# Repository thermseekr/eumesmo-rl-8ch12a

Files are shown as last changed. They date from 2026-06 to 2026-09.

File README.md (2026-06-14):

# eumesmo-rl-8ch12a

Relay board with 8x 24 VDC NO relays. This board is designed to be used togheter with [eumesmo-io-24v16ch](https://github.com/thermseekr/eumesmo-io-24v16ch), but can be driven by any 24V control circuit compatible with NPN inputs. It uses Omron 16A relays and is limited to 12A/channel per copper trace capacity.

The board is compatible with the SP7 DIN rail system from Metaltex.

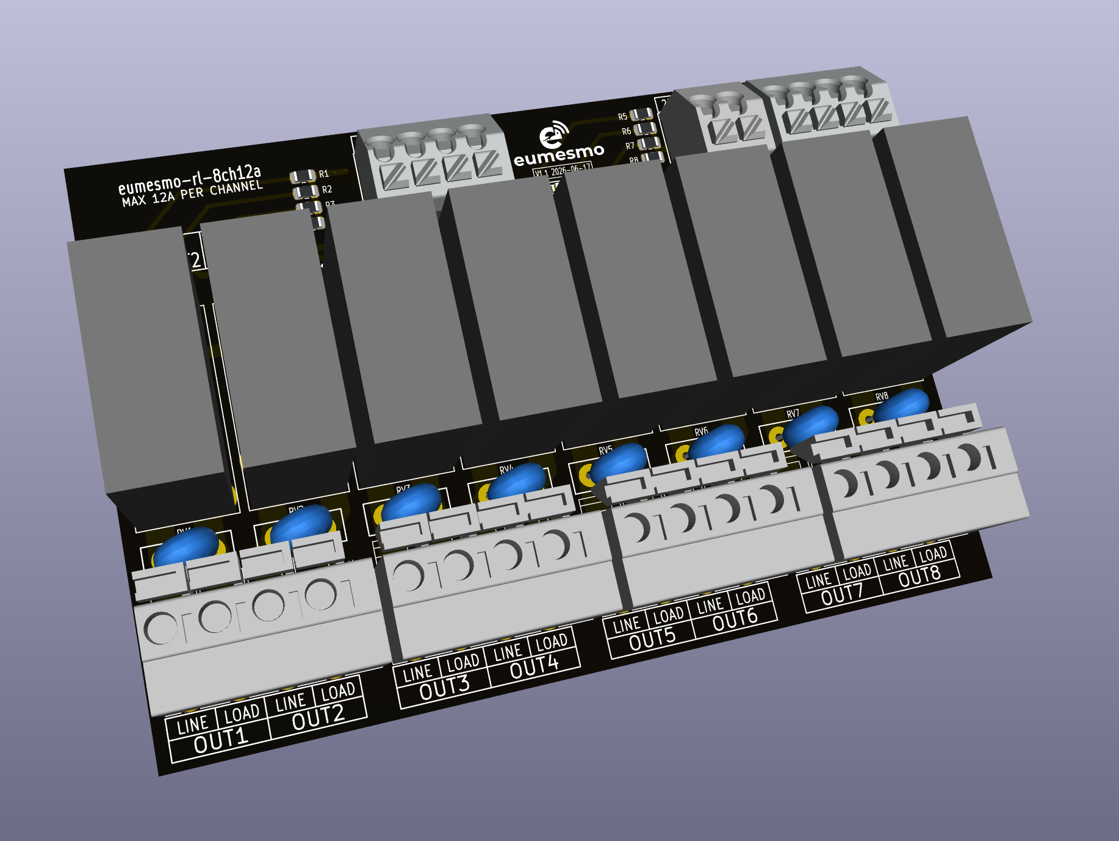
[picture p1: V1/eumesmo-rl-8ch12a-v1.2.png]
eumesmo-rl-8ch12a


## VERSION HISTORY

V1.2 - 2026/06/13 - Repository renamed from RELAY-24V-8CH-12A to eumesmo-rl-8ch12A to align the design with the eumesmo line of building automation products.

V1.1 - 2026/06/13 - Input terminal blocks replaced from 2.54mm to 3.5mm pitch for easier installation in the field.

V1.0 - 2024/11/24 - Initial release.

## LICENSE

This project is licensed under the [Creative Commons BY-NC 4.0 License](https://creativecommons.org/licenses/by-nc/4.0/).
Commercial use is not permitted without prior written consent. See the [LICENSE.txt](LICENSE.txt) file for details.

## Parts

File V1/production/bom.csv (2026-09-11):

Designator | Footprint | Quantity | Value | LCSC Part #
D1, D11, D13, D15, D3, D5, D7, D9 | 0603 | 8 | ORANGE/0603 | C2987557
D10, D12, D14, D16, D2, D4, D6, D8 | D_SOD-123 | 8 | 1N4148 | C81598
J1 | TerminalBlock_Wago_250-202_1x02_P3.5mm_45Degree | 1 | 250-202 | C2765061
J2, J3 | TerminalBlock_Wago_250-204_1x04_P3.5mm_45Degree | 2 | 250-204 | C2765063
J4, J5, J6, J7 | TerminalBlock_Dibo_DB142V-5.08-4P_1x04_P5.08mm_Vertical | 4 | DB142V-5.08-4P | C2898701
K1, K2, K3, K4, K5, K6, K7, K8 | Relay_SPST_Omron_G5PZ-1A | 8 | G5PZ-1A | C6719448
R1, R2, R3, R4, R5, R6, R7, R8 | 0805 | 8 | 10k/125mW | C17414
RV1, RV2, RV3, RV4, RV5, RV6, RV7, RV8 | RV_Disc_D9.50mm_W3.6mm_P5.08mm | 8 | 275VAC | C2761646

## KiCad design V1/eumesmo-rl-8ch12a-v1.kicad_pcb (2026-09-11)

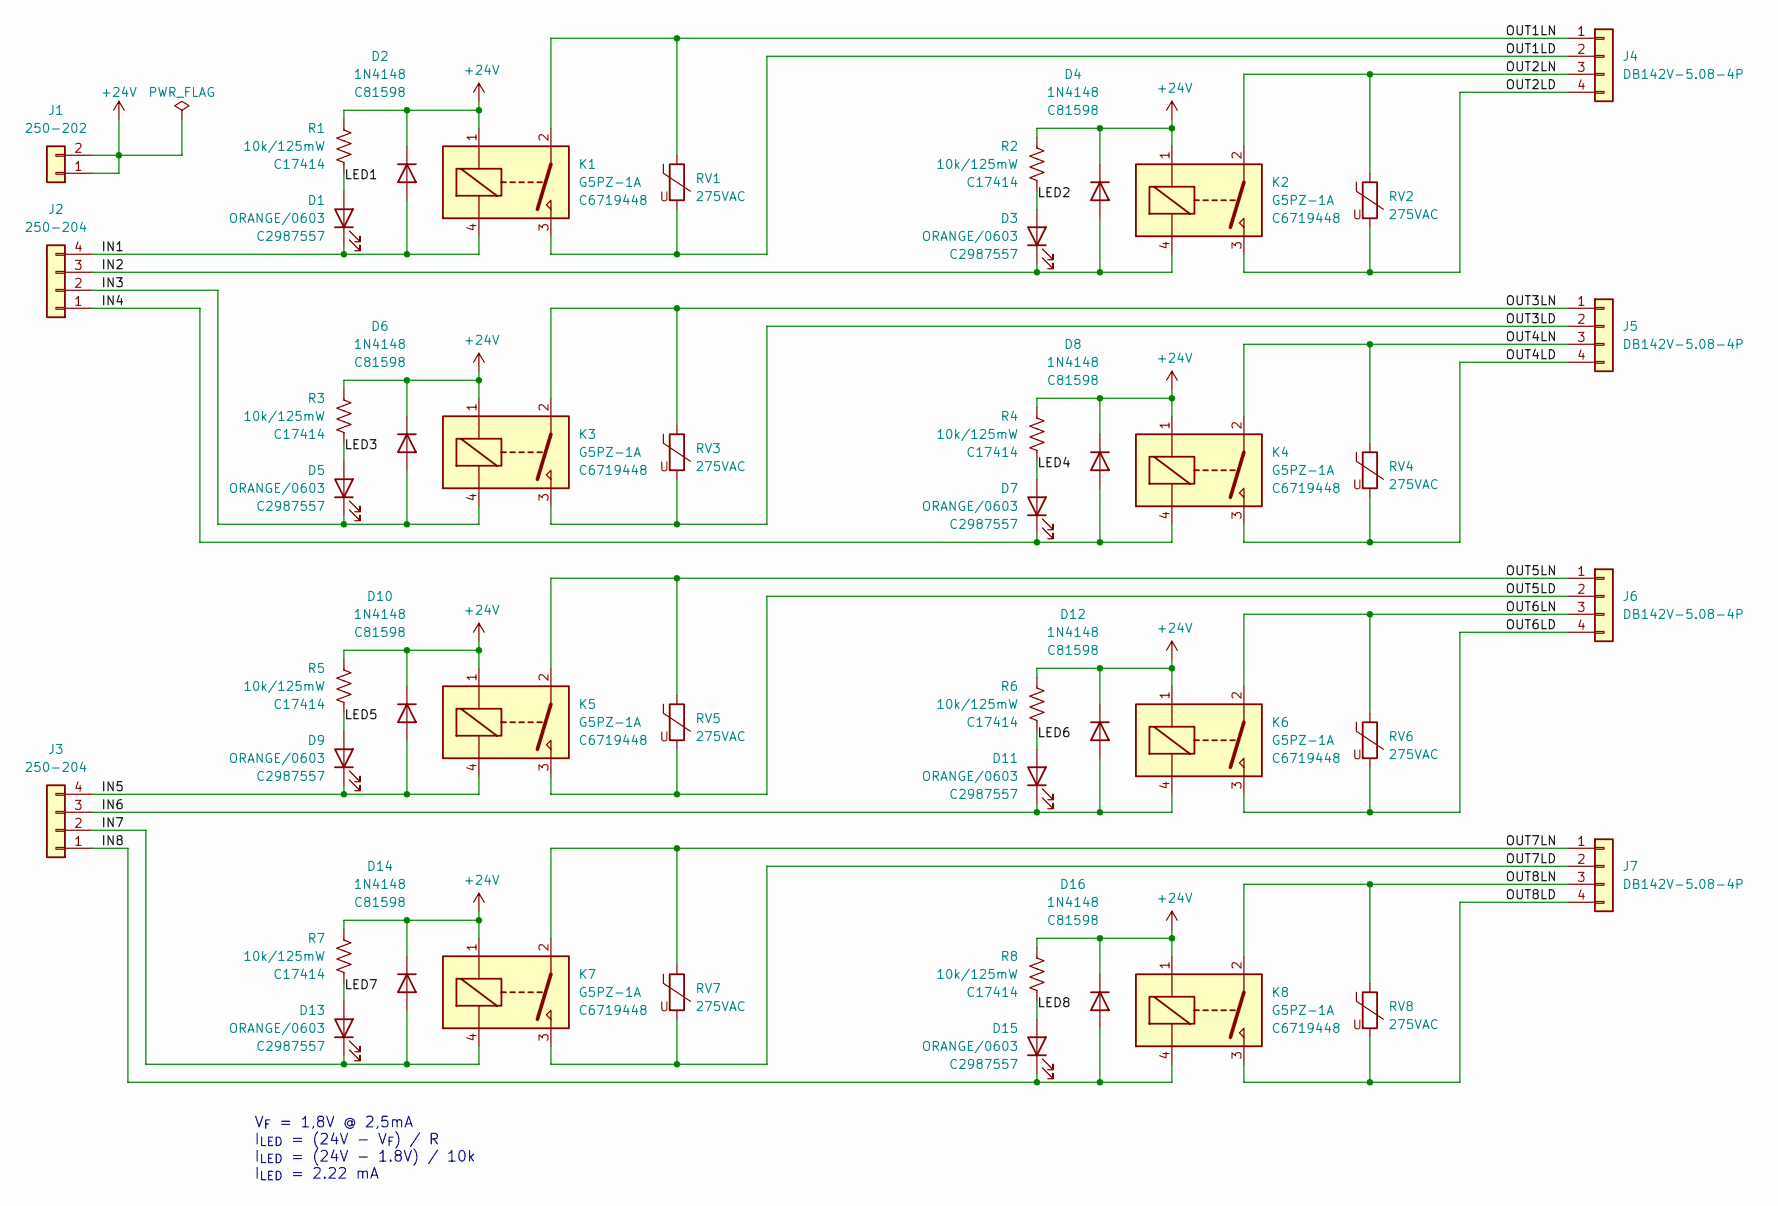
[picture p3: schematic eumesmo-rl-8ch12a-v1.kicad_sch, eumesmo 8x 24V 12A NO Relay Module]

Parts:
D1, D3, D5, D7, D9, D11, D13, D15: ORANGE/0603; LED_0603_1608Metric; Mfr PN 19-217/S2C-AL1M2VY/6T; LCSC Part # C2987557
D2, D4, D6, D8, D10, D12, D14, D16: 1N4148; D_SOD-123; Mfr PN 1N4148W; LCSC Part # C81598
J1: 250-202; TerminalBlock_Wago_250-202_1x02_P3.5mm_45Degree; Mfr PN 250-202; JLCPCB BOM 1
J2, J3: 250-204; TerminalBlock_Wago_250-204_1x04_P3.5mm_45Degree; Mfr PN 250-204; JLCPCB BOM 1
J4, J5, J6, J7: DB142V-5.08-4P; TerminalBlock_Dibo_DB142V-5.08-4P_1x04_P5.08mm_Vertical; Mfr PN DB142V-5.08-4P-GN; JLCPCB BOM 1
K1, K2, K3, K4, K5, K6, K7, K8: G5PZ-1A; Relay_SPST_Omron_G5PZ-1A; Mfr PN G5PZ-1A-E DC24V; JLCPCB BOM 1
R1, R2, R3, R4, R5, R6, R7, R8: 10k/125mW; R_0805_2012Metric; Mfr PN 0805W8F1002T5E; LCSC Part # C17414
RV1, RV2, RV3, RV4, RV5, RV6, RV7, RV8: 275VAC; RV_Disc_D9.50mm_W3.6mm_P5.08mm; Mfr PN RM07D431KC1IE100; JLCPCB BOM 1

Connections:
+24V: D2.1 (K), D4.1 (K), D6.1 (K), D8.1 (K), D10.1 (K), D12.1 (K), D14.1 (K), D16.1 (K), J1.1, J1.2, K1.1, K2.1, K3.1, K4.1, K5.1, K6.1, K7.1, K8.1, R1.1, R2.1, R3.1, R4.1, R5.1, R6.1, R7.1, R8.1
/IN1: D1.1 (K), D2.2 (A), J2.4, K1.4
/IN2: D3.1 (K), D4.2 (A), J2.3, K2.4
/IN3: D5.1 (K), D6.2 (A), J2.2, K3.4
/IN4: D7.1 (K), D8.2 (A), J2.1, K4.4
/IN5: D9.1 (K), D10.2 (A), J3.4, K5.4
/IN6: D11.1 (K), D12.2 (A), J3.3, K6.4
/IN7: D13.1 (K), D14.2 (A), J3.2, K7.4
/IN8: D15.1 (K), D16.2 (A), J3.1, K8.4
/LED1: D1.2 (A), R1.2
/LED2: D3.2 (A), R2.2
/LED3: D5.2 (A), R3.2
/LED4: D7.2 (A), R4.2
/LED5: D9.2 (A), R5.2
/LED6: D11.2 (A), R6.2
/LED7: D13.2 (A), R7.2
/LED8: D15.2 (A), R8.2
/OUT1LD: J4.2, K1.3, RV1.2
/OUT1LN: J4.1, K1.2, RV1.1
/OUT2LD: J4.4, K2.3, RV2.2
/OUT2LN: J4.3, K2.2, RV2.1
/OUT3LD: J5.2, K3.3, RV3.2
/OUT3LN: J5.1, K3.2, RV3.1
/OUT4LD: J5.4, K4.3, RV4.2
/OUT4LN: J5.3, K4.2, RV4.1
/OUT5LD: J6.2, K5.3, RV5.2
/OUT5LN: J6.1, K5.2, RV5.1
/OUT6LD: J6.4, K6.3, RV6.2
/OUT6LN: J6.3, K6.2, RV6.1
/OUT7LD: J7.2, K7.3, RV7.2
/OUT7LN: J7.1, K7.2, RV7.1
/OUT8LD: J7.4, K8.3, RV8.2
/OUT8LN: J7.3, K8.2, RV8.1

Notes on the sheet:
V_{F} = 1,8V @ 2,5mA I_{LED} = (24V - V_{F}) / R I_{LED} = (24V - 1.8V) / 10k I_{LED} = 2.22 mA

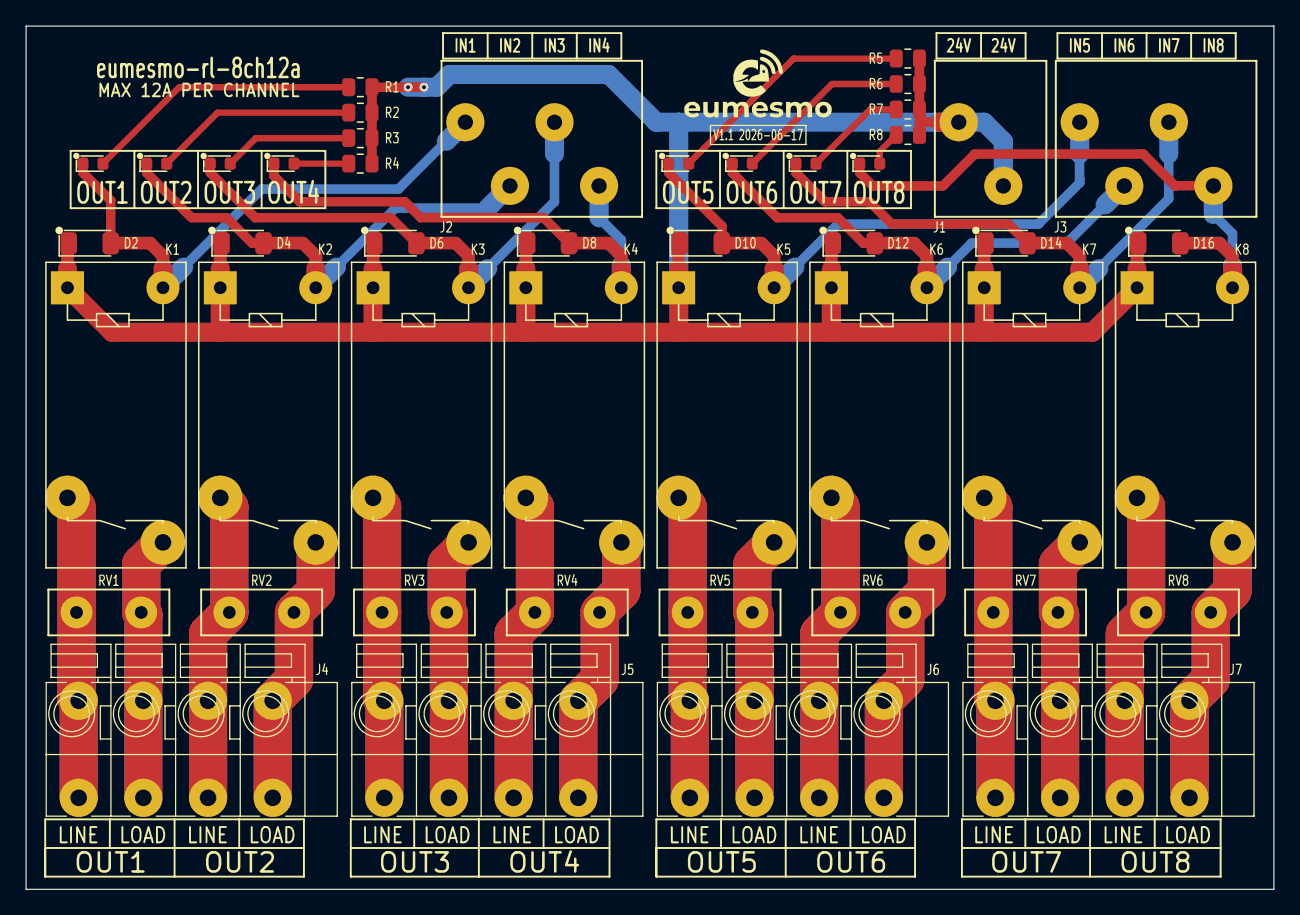
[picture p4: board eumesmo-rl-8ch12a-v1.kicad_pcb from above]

Board: 2 copper layers, 98.0 x 67.8 mm, 47 parts (0 on the bottom side), 33 nets.

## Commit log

2025-04-14 Prefab checks
    [bom.csv, designators.csv, positions.csv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]
2025-06-22 Updated connectors
    [relay-24v-8ch-12a-v1.kicad_pcb, relay-24v-8ch-12a-v1.kicad_sch]
2026-06-13 Small adjustments to silkscreen
    [relay-24v-8ch-12a-v1.kicad_pcb]
2026-06-17 Release V1.2.0
    [eumesmo-rl-8ch12a-v1.kicad_pcb, eumesmo-rl-8ch12a-v1.kicad_sch, positions.csv]
2026-07-06 Replaced 0603 size 10k resistor for 0805 size.
    [bom.csv, eumesmo-rl-8ch12a-v1.kicad_pcb, eumesmo-rl-8ch12a-v1.kicad_sch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]
2026-07-08 Replaced 0603 size 10k resistors for 0805 size.
2026-09-11 LEDs replaced for orange
    [bom.csv, eumesmo-rl-8ch12a-v1.kicad_pcb, eumesmo-rl-8ch12a-v1.kicad_sch]
